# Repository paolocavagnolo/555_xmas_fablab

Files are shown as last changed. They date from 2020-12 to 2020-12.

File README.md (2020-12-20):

 # 555_xmas_fablab

## Cosa c'è nel mio kit ?!
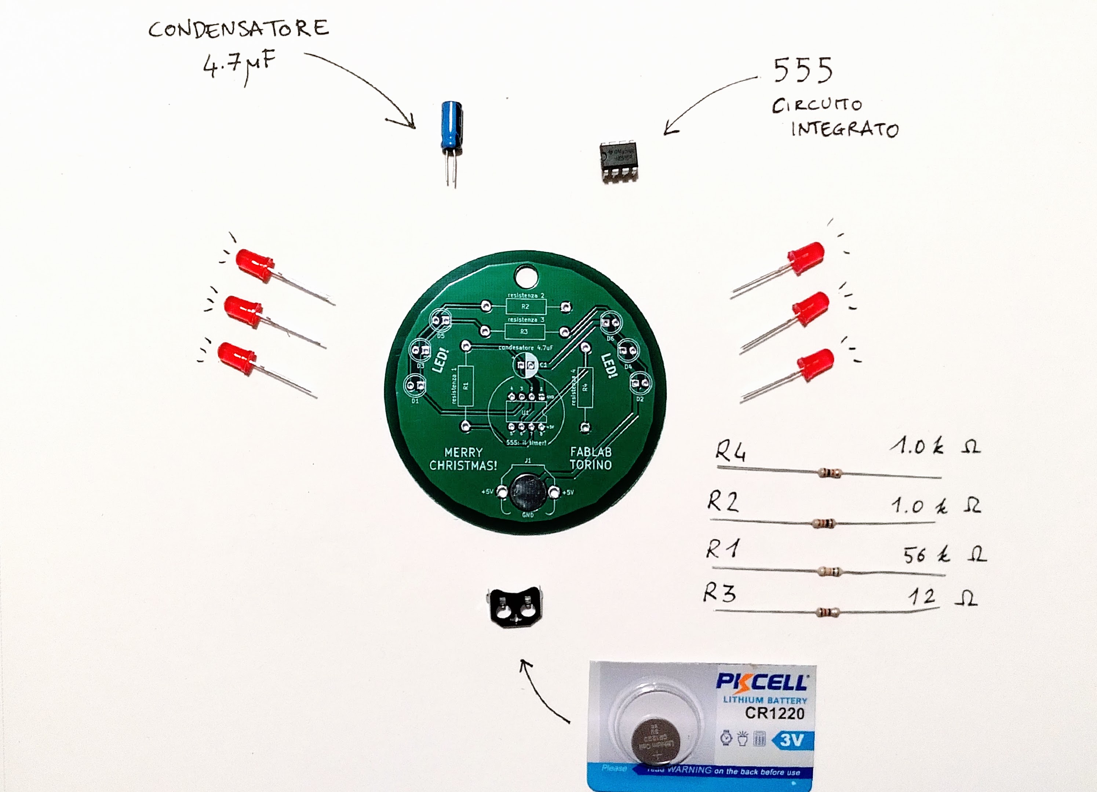
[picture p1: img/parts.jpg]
Parts


| Nome |Specifiche |  Q.tà |
|:---|:---:|---:|
| Led |  5mm | 6  |
| Timer | 555 | 1  |
| Condensatore  | 4uF | 1  |
| resistenza 1  | 56 kOhm | 1  |
| resistenza 2  | 1 kOhm | 1  |
| resistenza 3  | 12 Ohm | 1  |
| resistenza 4  | 1 kOhm | 1  |
| batteria | 1220 3V | 1  |
| portabatteria | 3001 | 1  |

## A cosa servono

### 555
E' il timer più famoso di tutti. Leggete [qui](https://it.wikipedia.org/wiki/NE555) per approfondire.

### Condesatore
Il condesatore in questo circuito regola la velocità del lampeggio tra i led, un condesatore con una capacità più grande farà lampeggiare i led più lentamente. Prova!

### Resistenze e alimentazione
Le resistenze regolano la corrente nel circuito. Se usate la pila da 3V per alimentare il circuito vedrete che i led di destra sono più deboli di quelli di sinistra. Questo dipende anche dal valore delle resistenze.
Se collegate l'alimentazione alla 5V (tagliando un cavetto USB e collegando il filo nero al - e il filo rosso al +5V) dovrete cambiare valore delle resistenze per non danneggiare i led e avere una buona luminosità, questi sono dei buoni valori:

| Nome | 5 Volt |  Q.tà |
|---|:---:|---:|
| resistenza 1  | 100 kOhm  | 1  |
| resistenza 2  | 1 kOhm | 1  |
| resistenza 3  | 1 kOhm | 1  |
| resistenza 4  | 1 kOhm | 1  |

## Come si monta il kit?
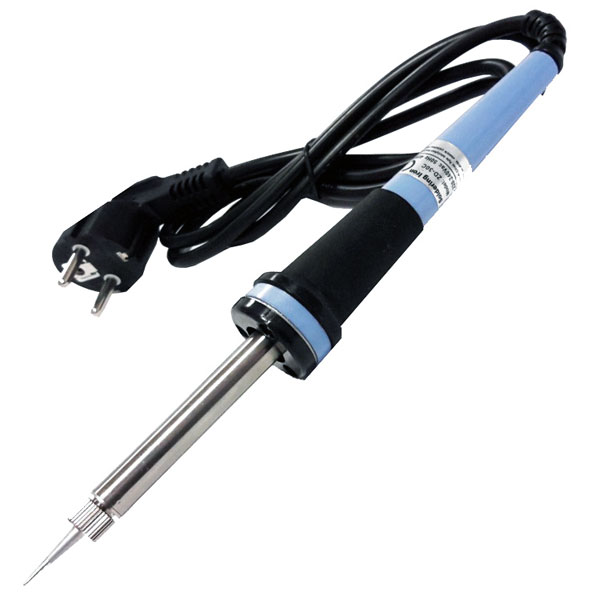
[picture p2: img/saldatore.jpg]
saldatore


Il kit è pronto per essere saldato, ti servirà un saldatore e dello stagno. Se non li hai ricevuti per regalo puoi provare a chiederli in prestito a qualcuno oppure venire al Fablab.

Se proprio non c'è nessuno che ti possa aiutare con le prime saldature puoi provare a cercare dei tutorial su youtube, ma qualcuno a fianco è più piacevole oltre che più sicuro.

### Saldare è l'unica possibilità?

Certo che no. Se hai intenzione di studiare il circuito cambiando componenti o valori delle resistenze è più facile usare una breadboard, la trovi in qualunque negozio di elettronica.
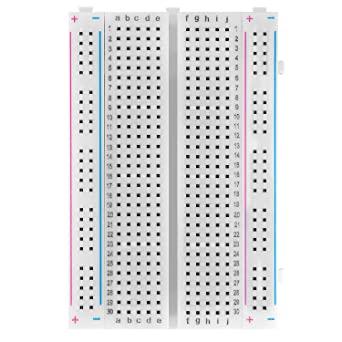
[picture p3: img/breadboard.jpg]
breadboard


### Come è fatto il circuito?

Per il circuito abbiamo preso spunto da qui:
https://www.petervis.com/GCSE_Design_and_Technology_Electronic_Products/simple-555-circuits/555-timer-dual-led-flasher.html

riadattandolo per farlo funzionare con una pila da 3V

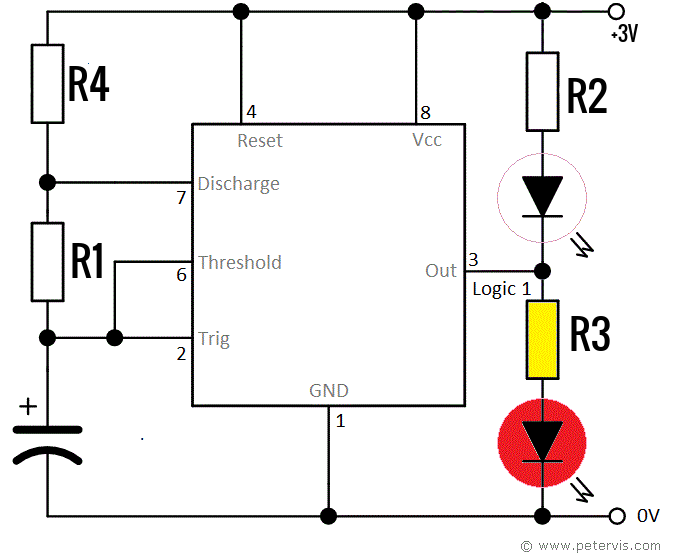
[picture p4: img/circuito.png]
circuito


## Note

### Alimentazione e durata batteria
Questo circuito non nasce per lavorare a 3V, ma a 5V. A 3 è un po' al limite, quindi basta che la tensioni si abbassi un pochettino e il led non si accenderanno più.

Le batterie, man mano che si scaricano, abbassano leggermente la tensione. Nel nostro caso questo significa che con 6 Led rossi dopo circa un giorno di funzionamento continuo i led si spegneranno.

### Differenza di luminosità nei led
E' normale che i led di destra risultino meno luminosi di quelli di sinistra, è una caratteristica del circuito che funziona a 3V. Lavorando a 5V e modificando il valore delle resistenze funzionerà tutto bene!

### Bella la pcb, se volessi modificarla o produrla da me?
Nella cartella kiCad in questo repository trovi tutti i file che abbiamo usato per far produrre la pcb.

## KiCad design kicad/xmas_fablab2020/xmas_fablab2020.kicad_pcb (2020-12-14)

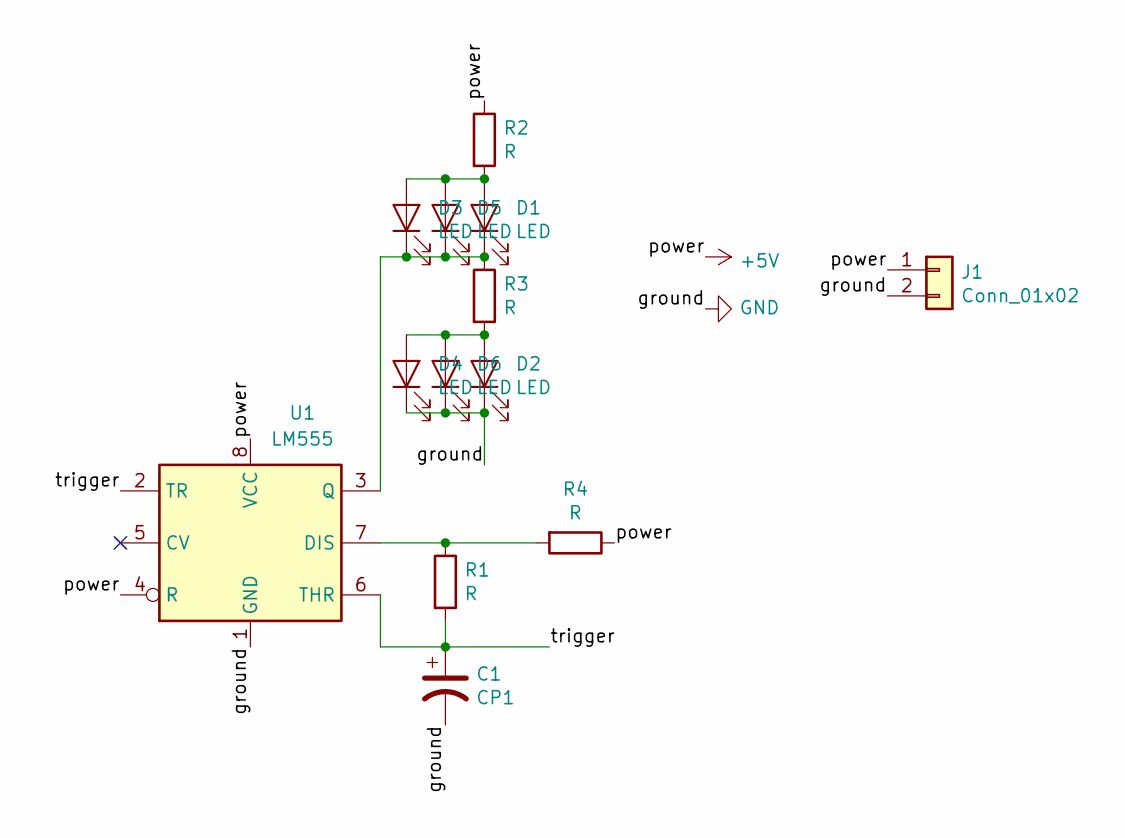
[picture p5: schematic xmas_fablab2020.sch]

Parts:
C1: CP1; CP_Radial_D6.3mm_P2.50mm
D1, D2, D3, D4, D5, D6: LED; LED_D5.0mm
J1: Conn_01x02; BatteryHolder_Keystone_3001_1x12mm
R1, R2, R3, R4: R; R_Axial_DIN0411_L9.9mm_D3.6mm_P20.32mm_Horizontal
U1: LM555; DIP-8_W7.62mm

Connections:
+5V: J1.1, R2.1, R4.1, U1.4 (R), U1.8 (VCC)
/trigger: C1.1, R1.2, U1.2 (TR), U1.6 (THR)
GND: C1.2, D2.1 (K), D4.1 (K), D6.1 (K), J1.2, U1.1 (GND)
unnamed: D1.1 (K), D3.1 (K), D5.1 (K), R3.1, U1.3 (Q)
unnamed: D1.2 (A), D3.2 (A), D5.2 (A), R2.2
unnamed: D2.2 (A), D4.2 (A), D6.2 (A), R3.2
unnamed: R1.1, R4.2, U1.7 (DIS)

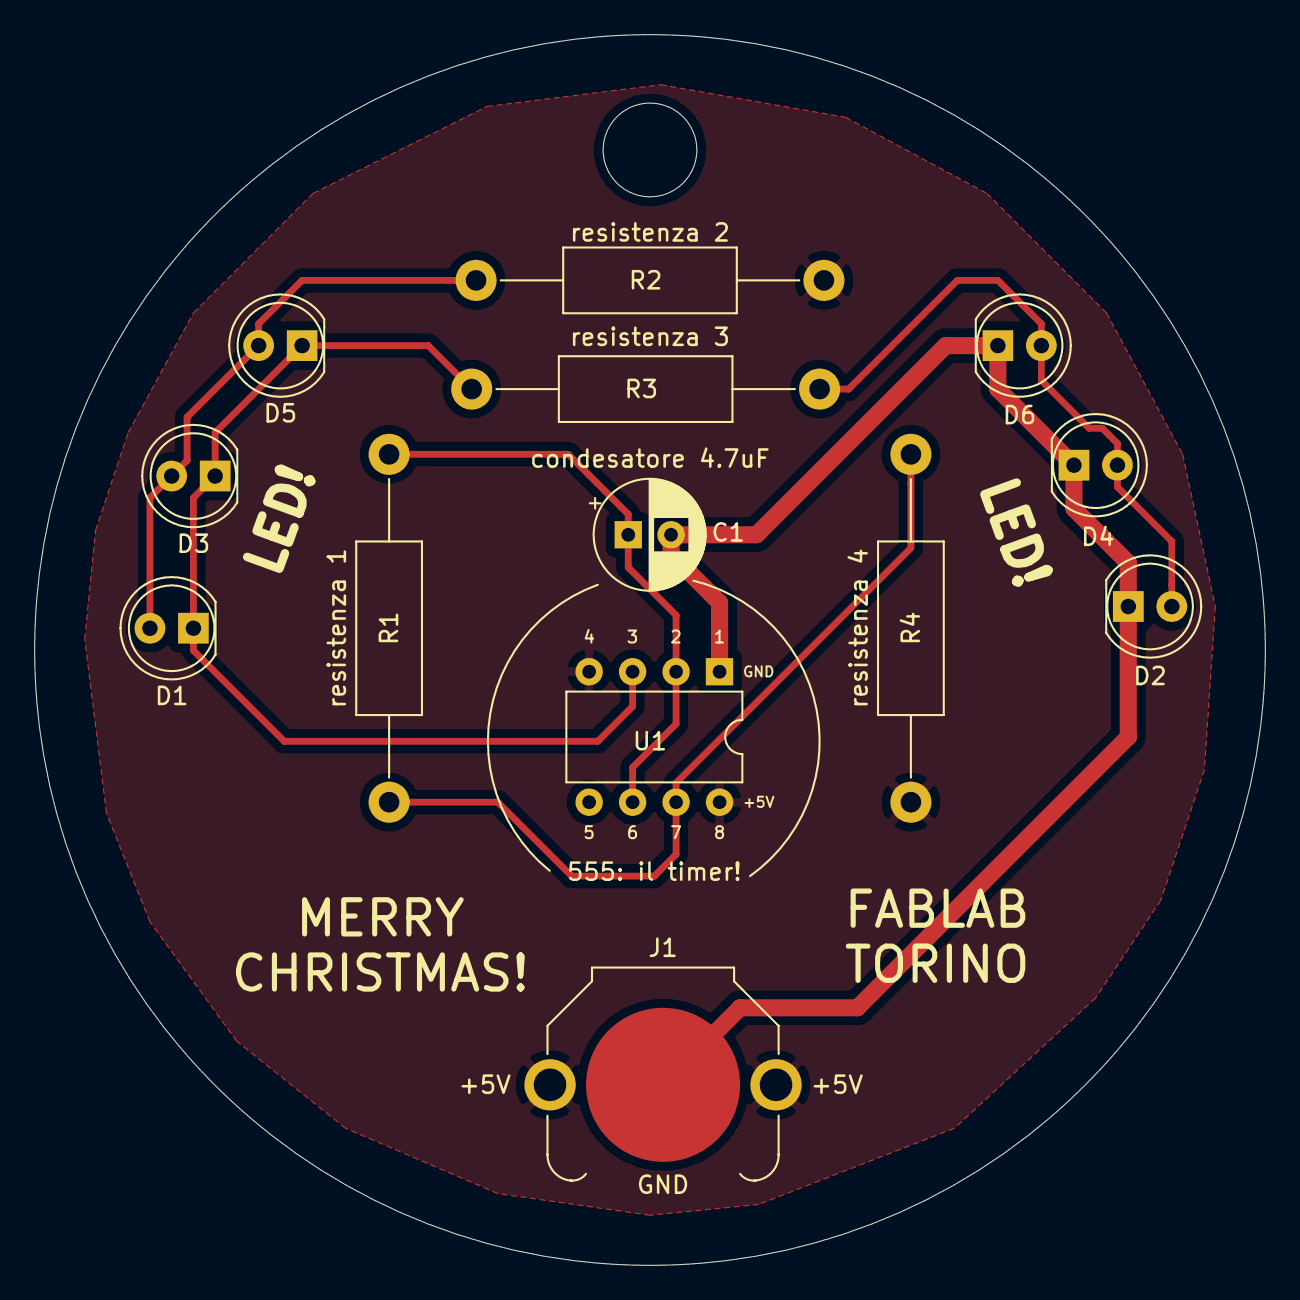
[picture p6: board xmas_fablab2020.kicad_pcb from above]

Board: 2 copper layers, 71.9 x 71.9 mm, 13 parts (0 on the bottom side), 7 nets.
